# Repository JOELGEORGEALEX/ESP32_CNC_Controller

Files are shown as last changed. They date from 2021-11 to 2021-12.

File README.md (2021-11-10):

# ESP32_CNC_Controller_VERSION_1.0
## ESP32 based CNC controller board
* The idea is to build a ESP32 GRBL based CNC controller board
### Objectives
* To build a wireless CNC controller board, so that the machines will become system independent
* Support 4 axis motors,SD_CARD,Axis limits/TMC_SPI.
* Flash the espwroom32 module directly from USB with FTDI chip,without use of hardware buttons
* Upload gcodesfiles /send gcodes live to CNC machines with the help of any systems
* Correct the issues that will surely occur in version 1.
### Version 1 Board
* As always jumper wires hanging here and there,as part of errors & corrections. But efforts were not wasted. Finally one awkward looking working board :)

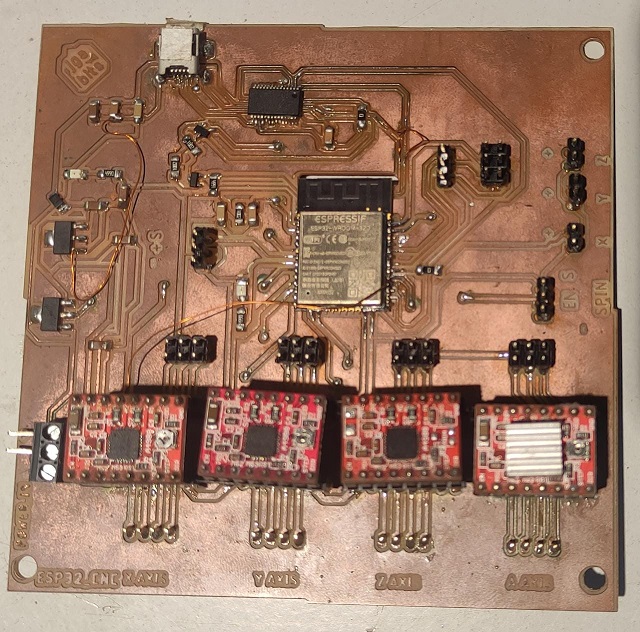
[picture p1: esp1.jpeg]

### Eagle schematic
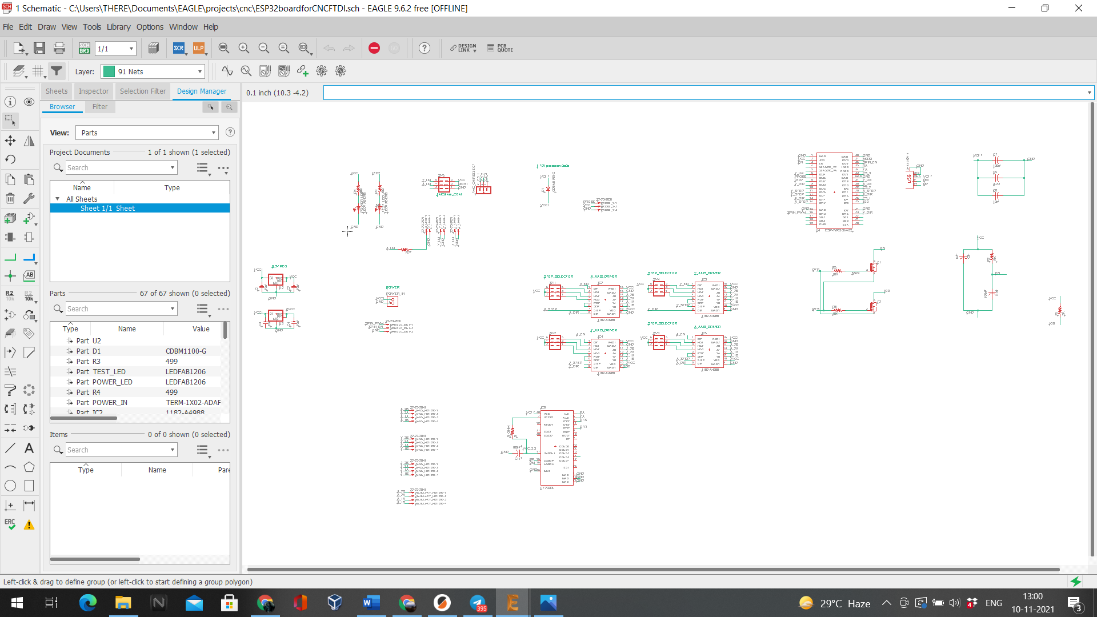
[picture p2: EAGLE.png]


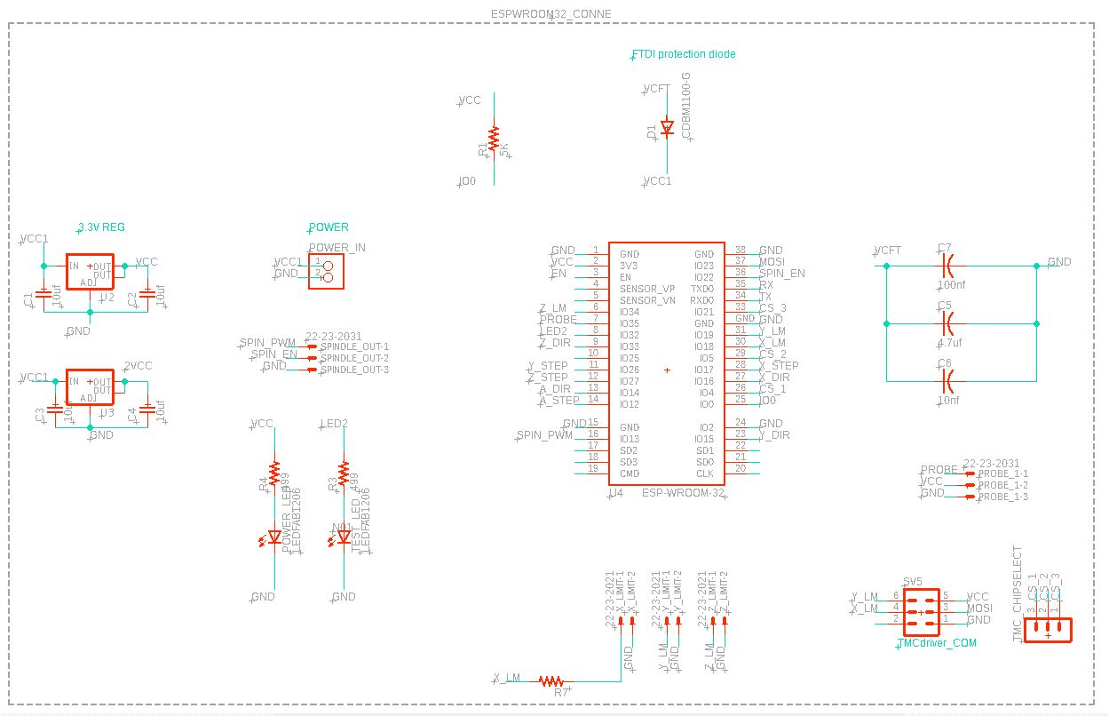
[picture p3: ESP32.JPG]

### FTDI 232RL flash circuit for ESPWROOM32
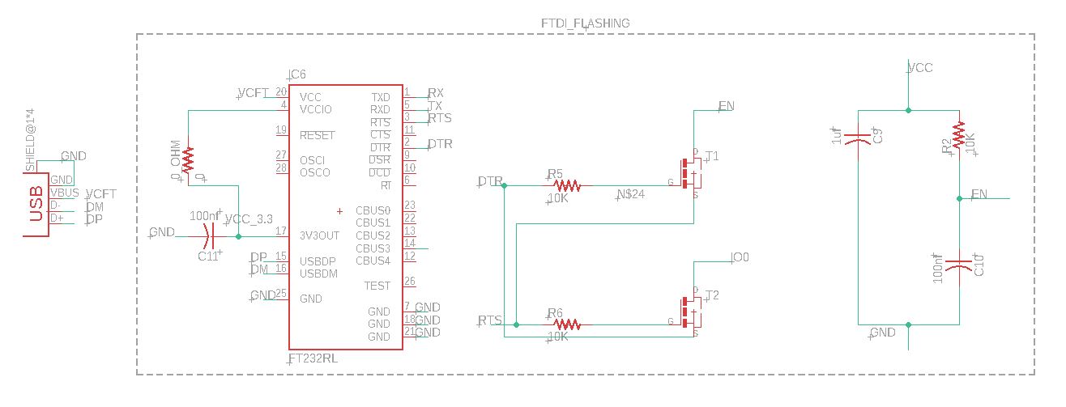
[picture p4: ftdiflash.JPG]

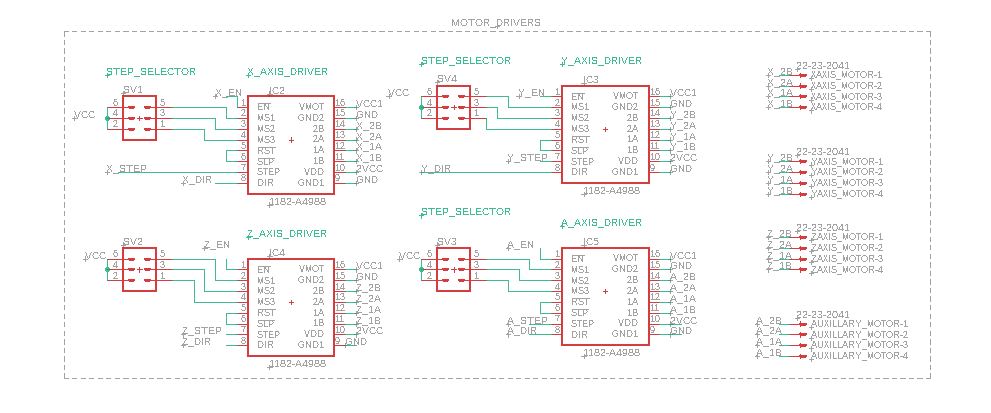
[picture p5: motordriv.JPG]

### Firmware flashing $###########Successsssss
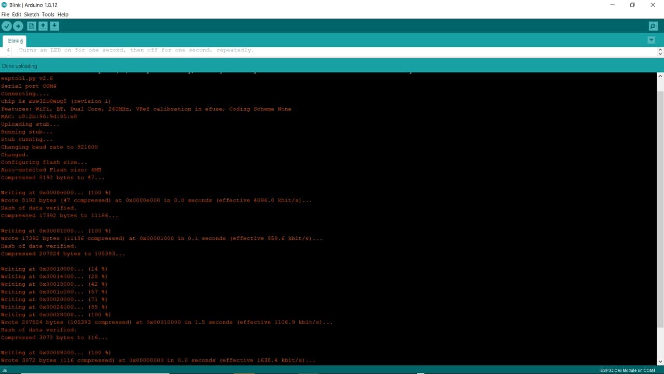
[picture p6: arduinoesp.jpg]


### Web interface for axis control,GCODE upload
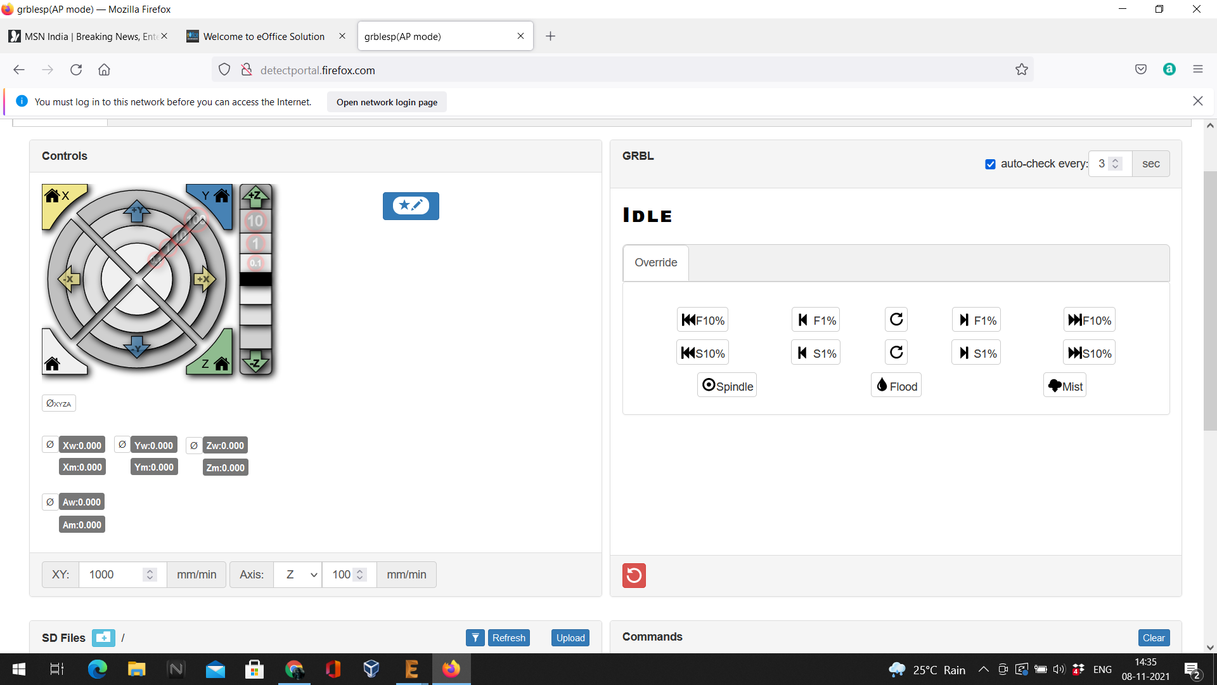
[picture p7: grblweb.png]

### SDCARD file manager for File read
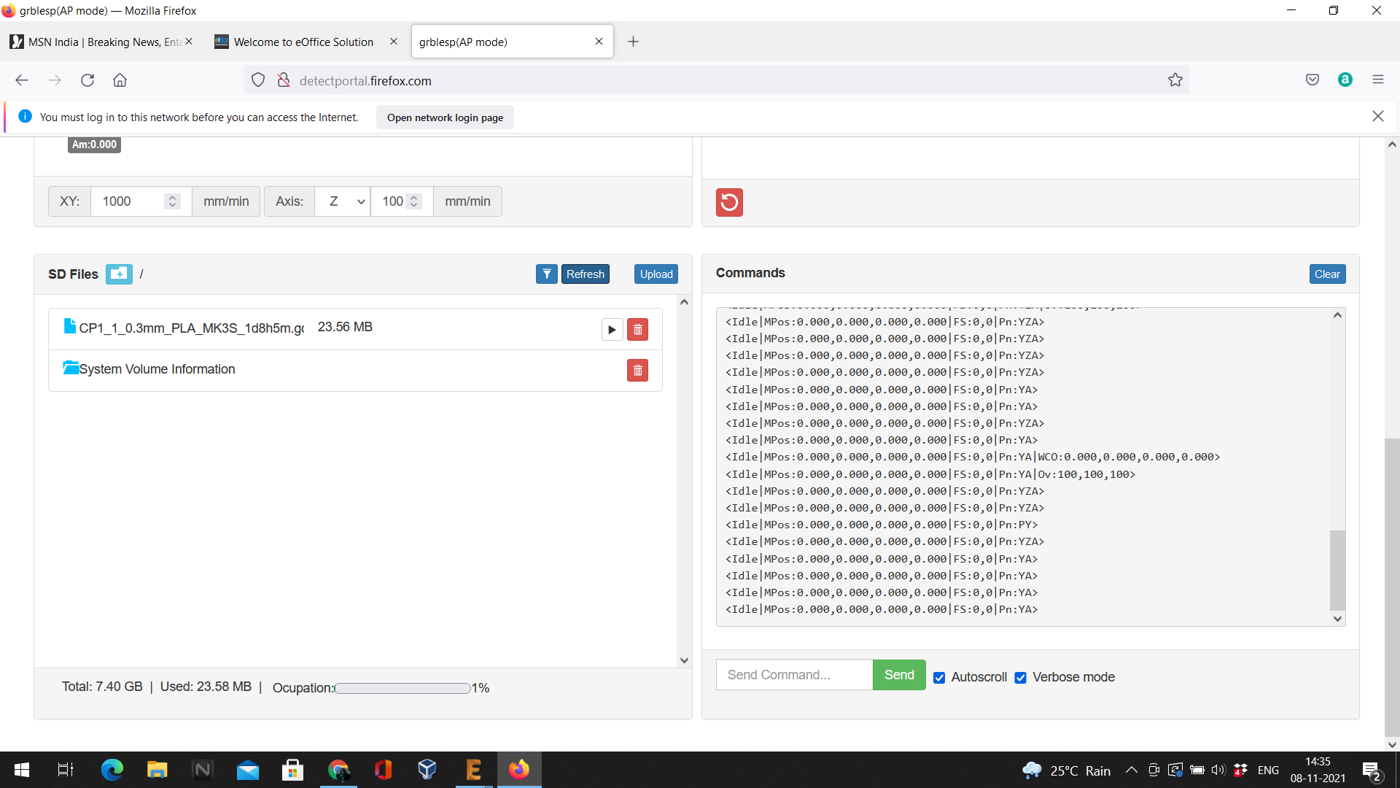
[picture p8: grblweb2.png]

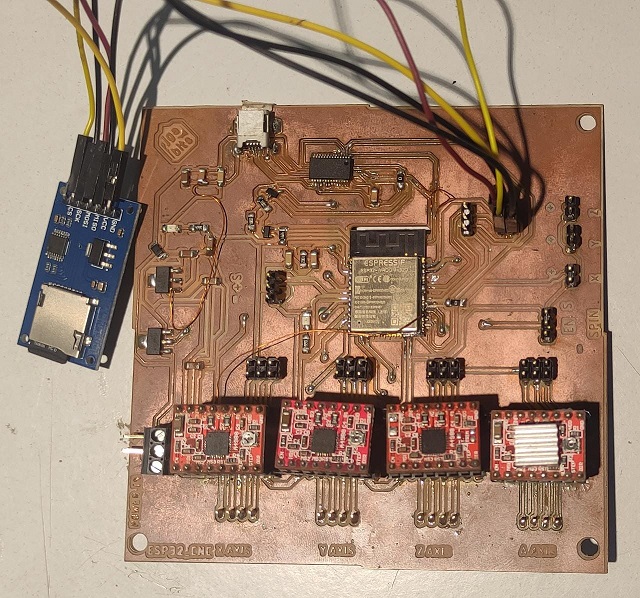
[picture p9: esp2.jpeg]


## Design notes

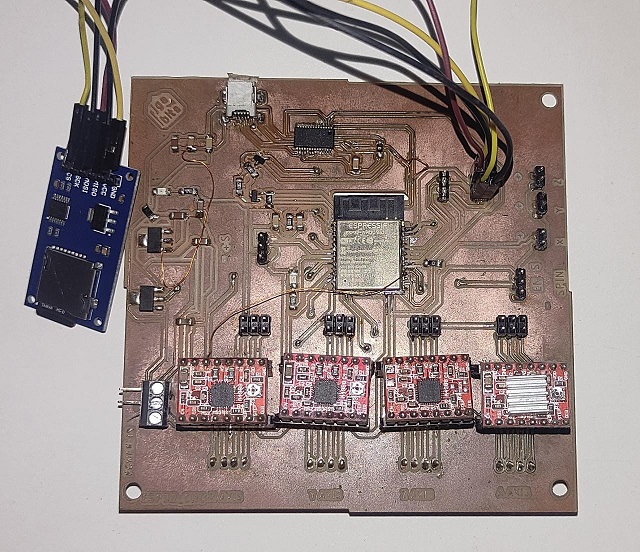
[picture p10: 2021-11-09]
esp3.jpeg

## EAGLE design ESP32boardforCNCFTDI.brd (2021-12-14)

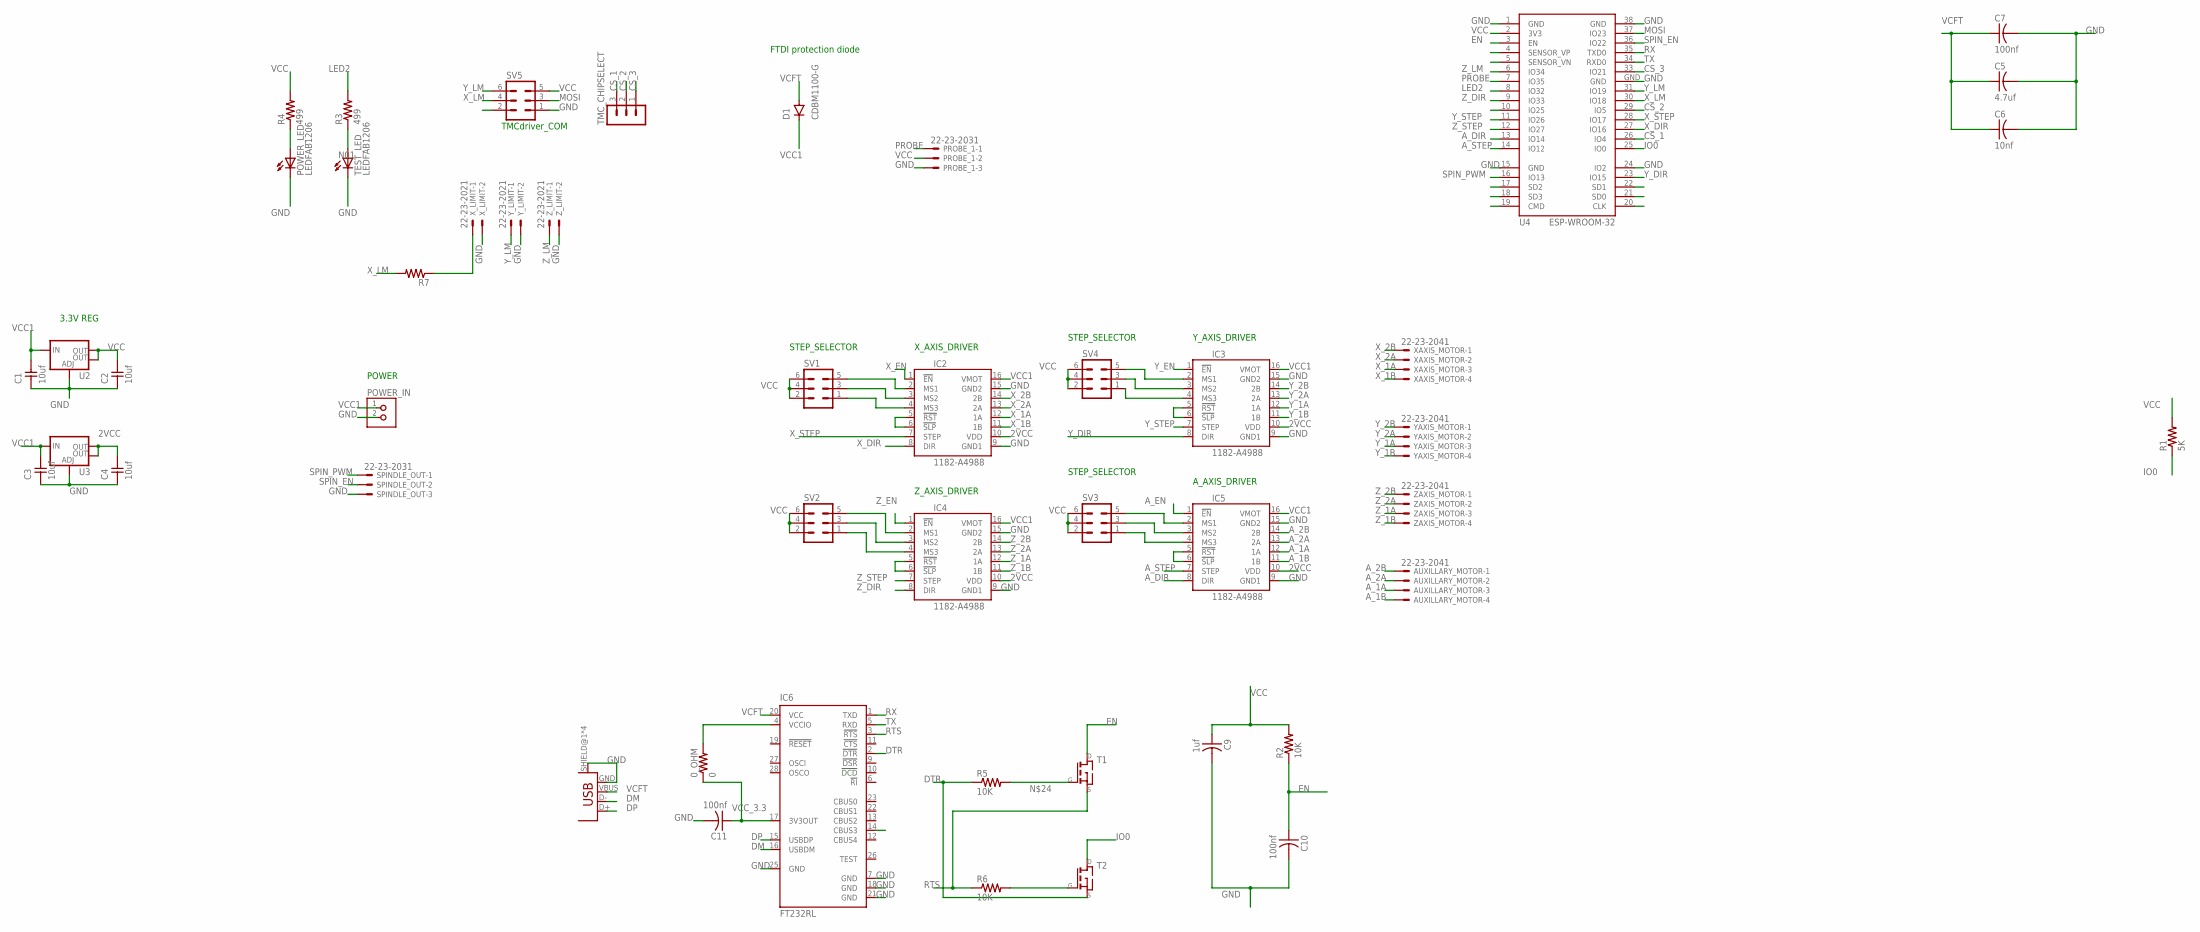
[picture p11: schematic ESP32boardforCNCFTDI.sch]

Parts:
0_OHM: 0; R1206FAB
AUXILLARY_MOTOR: 22-23-2041
C1, C2, C3, C4: 10uf; C1206FAB
C5: 4.7uf; C1206FAB
C6: 10nf; C1206FAB
C7, C10, C11: 100nf; C1206FAB
C9: 1uf; C1206FAB
D1: CDBM1100-G; MINI-SMA
IC2, IC3, IC4, IC5: 1182-A4988; A4988
IC6: FT232RL; SSOP28
POWER_IN: TERM-1X02-ADAFRUIT; 3.5MMTERM
POWER_LED: LEDFAB1206; LED1206FAB
PROBE_1: 22-23-2031
R1: 5K; R1206FAB
R2, R5, R6: 10K; R1206FAB
R3, R4: 499; R1206FAB
R7: RES-US1206FAB; R1206FAB
SPINDLE_OUT: 22-23-2031
SV1, SV2, SV3, SV4, SV5: MA03-2
T1, T2: NMOSFETSOT23; SOT-23
TEST_LED: LEDFAB1206; LED1206FAB
TMC_CHIPSELECT: MA03-1
U2, U3: V_REG_LM1117SOT223; SOT223
U4: ESP-WROOM-32
U$1: USB_MINIB
XAXIS_MOTOR: 22-23-2041
X_LIMIT: 22-23-2021
YAXIS_MOTOR: 22-23-2041
Y_LIMIT: 22-23-2021
ZAXIS_MOTOR: 22-23-2041
Z_LIMIT: 22-23-2021

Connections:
2VCC: C4.2, IC2.10 (VDD), IC3.10 (VDD), IC4.10 (VDD), IC5.10 (VDD), U3.2 (OUT), U3.4 (OUT)
A_1A: AUXILLARY_MOTOR.3, IC5.12 (1A)
A_1B: AUXILLARY_MOTOR.4, IC5.11 (1B)
A_2A: AUXILLARY_MOTOR.2, IC5.13 (2A)
A_2B: AUXILLARY_MOTOR.1, IC5.14 (2B)
A_DIR: IC5.8 (DIR), U4.13 (IO14)
A_EN: IC5.1 (!EN)
A_STEP: IC5.7 (STEP), U4.14 (IO12)
CS_1: TMC_CHIPSELECT.3, U4.26 (IO4)
CS_2: TMC_CHIPSELECT.2, U4.29 (IO5)
CS_3: TMC_CHIPSELECT.1, U4.33 (IO21)
DM: IC6.16 (USBDM), U$1.D-
DP: IC6.15 (USBDP), U$1.D+
DTR: IC6.2 (!DTR), R5.1, T2.2 (S)
EN: C10.1, R2.1, T1.1 (D), U4.3 (EN)
GND: C1.1, C2.1, C3.1, C4.1, C5.2, C6.2, C7.2, C9.2, C10.2, C11.2, IC2.9 (GND1), IC2.15 (GND2), IC3.9 (GND1), IC3.15 (GND2), IC4.9 (GND1), IC4.15 (GND2), IC5.9 (GND1), IC5.15 (GND2), IC6.7 (GND), IC6.18 (GND), IC6.21 (GND), IC6.25 (GND), POWER_IN.2, POWER_LED.2 (C), PROBE_1.3, SPINDLE_OUT.3, SV5.1, TEST_LED.2 (C), U2.1 (ADJ), U3.1 (ADJ), U4.1 (GND), U4.15 (GND), U4.24 (IO2), U4.38 (GND), U4.GND, U$1.GND, U$1.SHIELD@1 (SHIELD), U$1.SHIELD@2 (SHIELD), U$1.SHIELD@3 (SHIELD), U$1.SHIELD@4 (SHIELD), X_LIMIT.2, Y_LIMIT.2, Z_LIMIT.2
IO0: R1.1, T2.1 (D), U4.25 (IO0)
LED2: R3.2, U4.8 (IO32)
MOSI: SV5.3, U4.37 (IO23)
N01: R3.1, TEST_LED.1 (A)
unnamed: POWER_LED.1 (A), R4.1
unnamed: IC2.5 (!RST), IC2.6 (!SLP)
unnamed: IC3.5 (!RST), IC3.6 (!SLP)
unnamed: IC4.5 (!RST), IC4.6 (!SLP)
unnamed: IC5.5 (!RST), IC5.6 (!SLP)
unnamed: IC4.2 (MS1), SV2.5
unnamed: R7.1, X_LIMIT.1
unnamed: IC4.3 (MS2), SV2.3
unnamed: IC4.4 (MS3), SV2.1
unnamed: 0_OHM.2, IC6.4 (VCCIO)
unnamed: IC2.2 (MS1), SV1.5
unnamed: IC2.3 (MS2), SV1.3
unnamed: IC2.4 (MS3), SV1.1
unnamed: IC3.2 (MS1), SV4.5
unnamed: IC3.3 (MS2), SV4.3
unnamed: IC3.4 (MS3), SV4.1
unnamed: IC5.2 (MS1), SV3.5
unnamed: IC5.3 (MS2), SV3.3
unnamed: IC5.4 (MS3), SV3.1
unnamed: R5.2, T1.3 (G)
unnamed: R6.2, T2.3 (G)
PROBE: PROBE_1.1, U4.7 (IO35)
RTS: IC6.3 (!RTS), R6.1, T1.2 (S)
RX: IC6.1 (TXD), U4.35 (TXD0)
SPIN_EN: SPINDLE_OUT.2, U4.36 (IO22)
SPIN_PWM: SPINDLE_OUT.1, U4.16 (IO13)
TX: IC6.5 (RXD), U4.34 (RXD0)
VCC: C2.2, C9.1, PROBE_1.2, R1.2, R2.2, R4.2, SV1.2, SV1.4, SV1.6, SV2.2, SV2.4, SV2.6, SV3.2, SV3.4, SV3.6, SV4.2, SV4.4, SV4.6, SV5.5, U2.2 (OUT), U2.4 (OUT), U4.2 (3V3)
VCC1: C1.2, C3.2, D1.KATHODE, IC2.16 (VMOT), IC3.16 (VMOT), IC4.16 (VMOT), IC5.16 (VMOT), POWER_IN.1, U2.3 (IN), U3.3 (IN)
VCC_3.3: 0_OHM.1, C11.1, IC6.17 (3V3OUT)
VCFT: C5.1, C6.1, C7.1, D1.ANODE, IC6.20 (VCC), U$1.VBUS
X_1A: IC2.12 (1A), XAXIS_MOTOR.3
X_1B: IC2.11 (1B), XAXIS_MOTOR.4
X_2A: IC2.13 (2A), XAXIS_MOTOR.2
X_2B: IC2.14 (2B), XAXIS_MOTOR.1
X_DIR: IC2.8 (DIR), U4.27 (IO16)
X_EN: IC2.1 (!EN)
X_LM: R7.2, SV5.4, U4.30 (IO18)
X_STEP: IC2.7 (STEP), U4.28 (IO17)
Y_1A: IC3.12 (1A), YAXIS_MOTOR.3
Y_1B: IC3.11 (1B), YAXIS_MOTOR.4
Y_2A: IC3.13 (2A), YAXIS_MOTOR.2
Y_2B: IC3.14 (2B), YAXIS_MOTOR.1
Y_DIR: IC3.8 (DIR), U4.23 (IO15)
Y_EN: IC3.1 (!EN)
Y_LM: SV5.6, U4.31 (IO19), Y_LIMIT.1
Y_STEP: IC3.7 (STEP), U4.11 (IO26)
Z_1A: IC4.12 (1A), ZAXIS_MOTOR.3
Z_1B: IC4.11 (1B), ZAXIS_MOTOR.4
Z_2A: IC4.13 (2A), ZAXIS_MOTOR.2
Z_2B: IC4.14 (2B), ZAXIS_MOTOR.1
Z_DIR: IC4.8 (DIR), U4.9 (IO33)
Z_EN: IC4.1 (!EN)
Z_LM: U4.6 (IO34), Z_LIMIT.1
Z_STEP: IC4.7 (STEP), U4.12 (IO27)

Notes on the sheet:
FTDI protection diode
3.3V REG
POWER
X_AXIS_DRIVER
Y_AXIS_DRIVER
Z_AXIS_DRIVER
A_AXIS_DRIVER
STEP_SELECTOR
TMCdriver_COM

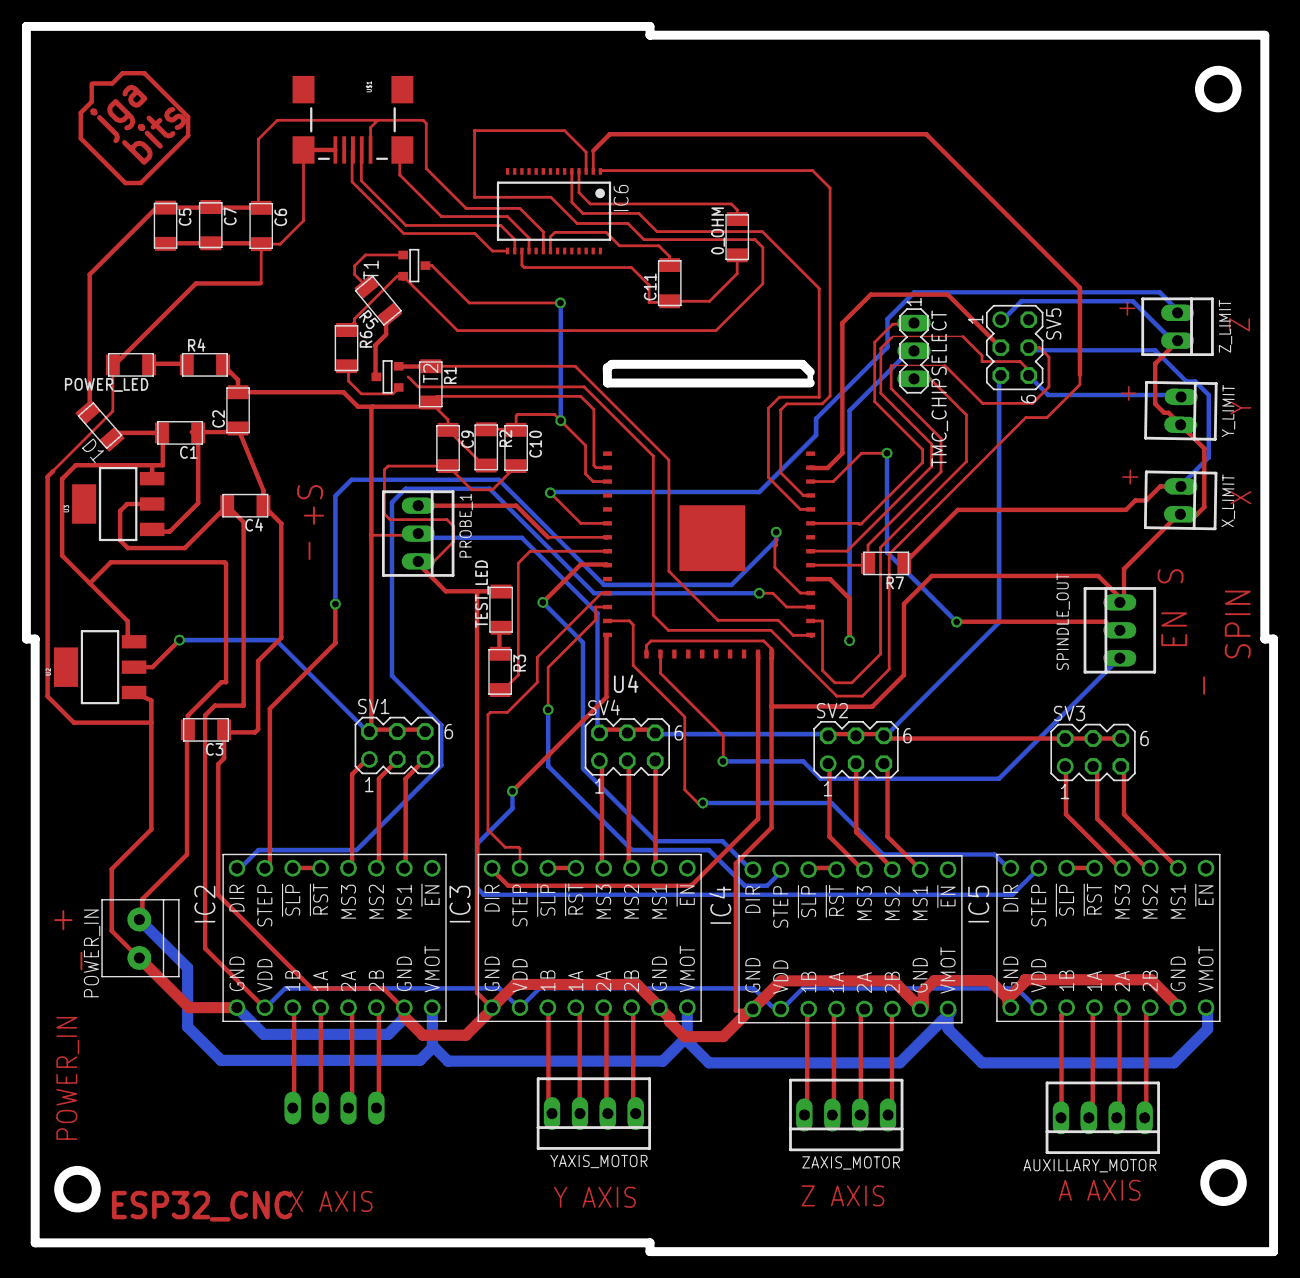
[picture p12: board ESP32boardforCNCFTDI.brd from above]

Board: 2 copper layers, 113.6 x 111.6 mm, 48 parts (1 on the bottom side), 71 nets.

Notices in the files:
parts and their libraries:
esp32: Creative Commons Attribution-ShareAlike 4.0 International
